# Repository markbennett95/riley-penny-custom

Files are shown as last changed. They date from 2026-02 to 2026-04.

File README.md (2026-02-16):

# Custom Dual OD - Riley Penney

Custom dual drive in a 1590BB - Called the "Chinook Overdrive", it features a Zendrive on one side, and a modified BD-2 on the the other.

## v1.0.0-build
1590BB encl. Works with `1590BB-2` of the [Dual Effect Order Switching Board](https://github.com/markbennett95/dual-effect-order-switching-board). Zendrive schematic is unchanged, using the "version" switch and a DG412. The BD-2 is heavily modified from the original; It features an active baxendall 2-band tone stack, and a gyrator-based 3-way "Mids" switch. Some zener diodes were added in the feedback path of the second gain stage, which went a long ways in cleaning up some of the fizziness inherent in the original version.

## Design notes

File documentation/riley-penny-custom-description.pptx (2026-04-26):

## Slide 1

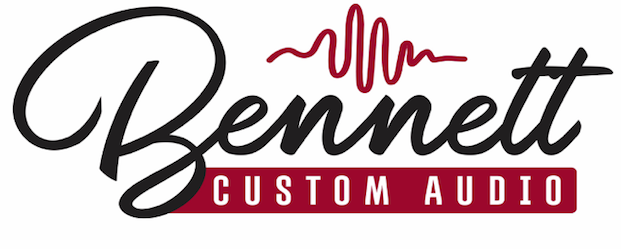
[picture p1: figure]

“Chinook”
Custom Dual Overdrive

Introduction:
This custom-designed pedal features two independent overdrive circuits with order switching. The overdrives are modified versions of the Boss BD2 (“BD2”), and the Zendrive by Hermida Audio (“Zendrive”). The Chinook must be powered by a 9-18VDC, centre-negative power supply, capable of delivering 100mA of current – It does not have room for a battery inside. Like all our pedals, The Chinook was designed and assembled by hand in St. John’s, NL.

Controls:
- BD2 VOL: Controls the output level of the BD2. Turn it up for a louder signal.
- BD2 GAIN: Determines the amount of distortion in the BD2. Turn it up for a more distorted, sustaining tone with more harmonics. Turn it down for a cleaner sound.
- BD2 BASS: Controls the amount of bass in the BD2. It has a centre-notch for a flat response, and may be boost or cut from there by turning it up or down.
- BD2 MIDS: A 3-position switch that sets the mid-range response of the pedal. The CENTRE position gives a flat response. DOWN gives a scooped mid, and UP gives a pushed mids response.
- BD2 TREBLE: Controls the amount of treble in the BD2. It has a centre-notch for a flat response, and may be boost or cut from there by turning it up or down.
- ZEN VOL: Controls the output level of the Zendrive. Turn it up for a louder signal.
- ZEN GAIN: Determines the amount of distortion in the Zendrive. Turn it up for a more distorted, sustaining tone with more harmonics. Turn it down for a cleaner sound.
- ZEN TONE: Controls how warm or bright the tone will be. Turn it up for a bright sound.
- ZEN VERSION SWITCH: Sets the “version” of the Zendrive. Version I is brighter, with asymmetric clipping, less bass, and less overall gain. Version II has more gain, bass, and symmetric clipping for a warmer, fuzzier tone.
- ZEN VOICE: Sets the pre-gain bass of the Zendrive. Turning it down gives a warmer, less distorted sound. Turning it up gives a brighter sound with more overall gain.
- BD2 Footswitch: Toggles the BD2 on or off with true bypass. IF the LED next to it is illuminated, your signal is passing into the effect.
- Order Switch: Sets the order of the two overdrive circuits. UP puts the Zendrive before the BD2 in your signal chain, DOWN puts the BD2 before the Zendrive.
- ZEN Footswitch: Toggles the Zendrive on or off with true bypass. IF the LED next to it is illuminated, your signal is passing into the effect.

V1.0.0

www.bennettcustomaudio.ca
bennettcustomaudio@gmail.com

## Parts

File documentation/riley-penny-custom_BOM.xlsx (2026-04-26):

Value | Qty | Reference | Footprint
2.2k | 4 | R21,R25,R31,R35 | Resistor_SMD:R_0603_1608Metric_Pad0.98x0.95mm_HandSolder
4.7k | 2 | R22,R32 | Resistor_SMD:R_0603_1608Metric_Pad0.98x0.95mm_HandSolder
10k | 5 | R1,R17,R18,R60,R61 | Resistor_SMD:R_0805_2012Metric_Pad1.20x1.40mm_HandSolder
22k | 2 | R2,R3 | Resistor_SMD:R_0805_2012Metric_Pad1.20x1.40mm_HandSolder
33k | 1 | R52 | Resistor_SMD:R_0805_2012Metric_Pad1.20x1.40mm_HandSolder
1M | 3 | R20,R49,R51 | Resistor_SMD:R_0805_2012Metric_Pad1.20x1.40mm_HandSolder
10M | 1 | R6 | Resistor_SMD:R_0805_2012Metric_Pad1.20x1.40mm_HandSolder
47pF | 4 | C17,C18,C31,C35 | Capacitor_SMD:C_0603_1608Metric_Pad1.08x0.95mm_HandSolder
100pF | 3 | C6,C24,C25 | Capacitor_SMD:C_0603_1608Metric_Pad1.08x0.95mm_HandSolder
470pF | 1 | C9 | Capacitor_SMD:C_0603_1608Metric_Pad1.08x0.95mm_HandSolder
100nF | 3 | C14,C44,C45 | Capacitor_SMD:C_0603_1608Metric_Pad1.08x0.95mm_HandSolder
1uF | 1 | C11 | Capacitor_SMD:C_0805_2012Metric_Pad1.18x1.45mm_HandSolder
FerriteBead_Small | 3 | FB1,FB2,FB3 | Inductor_SMD:L_0805_2012Metric_Pad1.15x1.40mm_HandSolder
9V1 Zener | 1 | D1 | Diode_SMD:D_SOD-323_HandSoldering
Q_PMOS_GSD | 1 | Q1 | Package_TO_SOT_SMD:SOT-23_Handsoldering
BC857C | 2 | Q6,Q8 | Package_TO_SOT_SMD:SOT-23_Handsoldering
BC847C | 1 | Q9 | Package_TO_SOT_SMD:SOT-23_Handsoldering
2N7002 | 3 | Q2,Q3,Q4 | Package_TO_SOT_SMD:SOT-23_Handsoldering
LS844 | 2 | Q5,Q7 | Package_TO_SOT_SMD:SOT-23-6_Handsoldering
OPA1642 | 1 | U2 | Package_SO:SOIC-8_3.9x4.9mm_P1.27mm
TLV9352 | 2 | U3,U4 | Package_SO:SOIC-8_3.9x4.9mm_P1.27mm
DG412xY | 1 | U1 | Package_SO:SOIC-16_3.9x9.9mm_P1.27mm
1k | 4 | R8,R14,R36,R50 | bca-footprints:R_L3.6mm_D1.6mm_P5.00mm_Horizontal
1.5k | 2 | R23,R56 | bca-footprints:R_L3.6mm_D1.6mm_P5.00mm_Horizontal
3.9k | 2 | R33,R39 | bca-footprints:R_L3.6mm_D1.6mm_P5.00mm_Horizontal
5.6k | 2 | R38,R54 | bca-footprints:R_L3.6mm_D1.6mm_P5.00mm_Horizontal
6.8k | 3 | R37,R47 | bca-footprints:R_L3.6mm_D1.6mm_P5.00mm_Horizontal
10k | 8 | R7,R10,R11,R13,R19,R44,R58,R59 | bca-footprints:R_L3.6mm_D1.6mm_P5.00mm_Horizontal
15k | 4 | R24,R29,R42,R45 | bca-footprints:R_L3.6mm_D1.6mm_P5.00mm_Horizontal
18k | 1 | R12 | bca-footprints:R_L3.6mm_D1.6mm_P5.00mm_Horizontal
22k | 3 | R34,R43,R46 | bca-footprints:R_L3.6mm_D1.6mm_P5.00mm_Horizontal
56k | 2 | R26,R53 | bca-footprints:R_L3.6mm_D1.6mm_P5.00mm_Horizontal
100k | 3 | R15,R16,R57 | bca-footprints:R_L3.6mm_D1.6mm_P5.00mm_Horizontal
180k | 1 | R41 | bca-footprints:R_L3.6mm_D1.6mm_P5.00mm_Horizontal
330k | 1 | R27 | bca-footprints:R_L3.6mm_D1.6mm_P5.00mm_Horizontal
470k | 5 | R5,R30,R40,R48,R55 | bca-footprints:R_L3.6mm_D1.6mm_P5.00mm_Horizontal
680k | 1 | R9 | bca-footprints:R_L3.6mm_D1.6mm_P5.00mm_Horizontal
1M | 1 | R28 | bca-footprints:R_L3.6mm_D1.6mm_P5.00mm_Horizontal
2.2M | 1 | R4 | bca-footprints:R_L3.6mm_D1.6mm_P5.00mm_Horizontal
1N4148 | 5 | D5,D7,D8,D11,D12 | bca-footprints:Diode_DO-35_P5.00mm
1N5711 | 4 | D2,D3,D4,D6 | bca-footprints:Diode_DO-35_P5.00mm
3v3 Zener | 1 | D9 | bca-footprints:Diode_Zener_DO-35_P5.00mm
4v7 Zener | 1 | D10 | bca-footprints:Diode_Zener_DO-35_P5.00mm
220pF | 1 | C19 | bca-footprints:C_Ceramic_L4.0mm_W2.5mm_P2.50mm
3.3nF | 1 | C7 | bca-footprints:C_Film_L7.2mm_W2.5mm_P5.00mm
3.9nF | 3 | C22,C33,C39 | bca-footprints:C_Film_L7.2mm_W2.5mm_P5.00mm
5.6nF | 3 | C26,C27,C40 | bca-footprints:C_Film_L7.2mm_W2.5mm_P5.00mm
8.2nF | 1 | C36 | bca-footprints:C_Film_L7.2mm_W2.5mm_P5.00mm
15nF | 2 | C34,C37 | bca-footprints:C_Film_L7.2mm_W2.5mm_P5.00mm
18nF | 2 | C15,C28 | bca-footprints:C_Film_L7.2mm_W2.5mm_P5.00mm
33nF | 2 | C30,C38 | bca-footprints:C_Film_L7.2mm_W2.5mm_P5.00mm
47nF | 1 | C21 | bca-footprints:C_Film_L7.2mm_W2.5mm_P5.00mm
68nF | 1 | C29 | bca-footprints:C_Film_L7.2mm_W2.5mm_P5.00mm
0.1uF | 1 | C20 | bca-footprints:C_Film_L7.2mm_W2.5mm_P5.00mm
0.15uF | 1 | C16 | bca-footprints:C_Film_L7.2mm_W3.5mm_P5.00mm
0.22uF | 3 | C4,C5,C8 | bca-footprints:C_Film_L7.2mm_W3.5mm_P5.00mm
0.47uF | 2 | C3,C10 | bca-footprints:C_Film_L7.2mm_W3.5mm_P5.00mm
1uF | 1 | C23 | bca-footprints:C_Film_L7.2mm_W3.5mm_P5.00mm
10uF | 2 | C32,C41 | bca-footprints:CP_Radial_D4.0mm_P1.50mm
100uF | 6 | C1,C2,C12,C13,C42,C43 | bca-footprints:CP_Radial_D6.3mm_P2.50mm
SW_DIP_SPDT_2pos | 1 | SW3 | bca-footprints:DIP-8_W7.62mm_Socket
Barrel_Jack_Switch | 1 | J1 | bca-footprints:DC_Jack_DC005
AudioJack_TRS | 2 | J2,J3 | bca-footprints:Rean_NYS215
GNDSpring | 1 | G1 | bca-footprints:Keystone_628
10kC | 1 | RV1 | bca-footprints:R_POT
50kB | 1 | RV3 | bca-footprints:R_POT
100kA | 2 | RV4,RV6 | bca-footprints:R_POT
100k-CD | 2 | RV7,RV8 | bca-footprints:R_POT
1MA | 1 | RV2 | bca-footprints:R_POT
250kA | 1 | RV5 | bca-footprints:R_POT_DUAL
SW_DPDT_x2 | 1 | SW2 | bca-footprints:SW_Toggle_DPDT_SolderLug
SW_SPDT | 1 | SW1 | bca-footprints:SW_Toggle_SPDT_SolderLug

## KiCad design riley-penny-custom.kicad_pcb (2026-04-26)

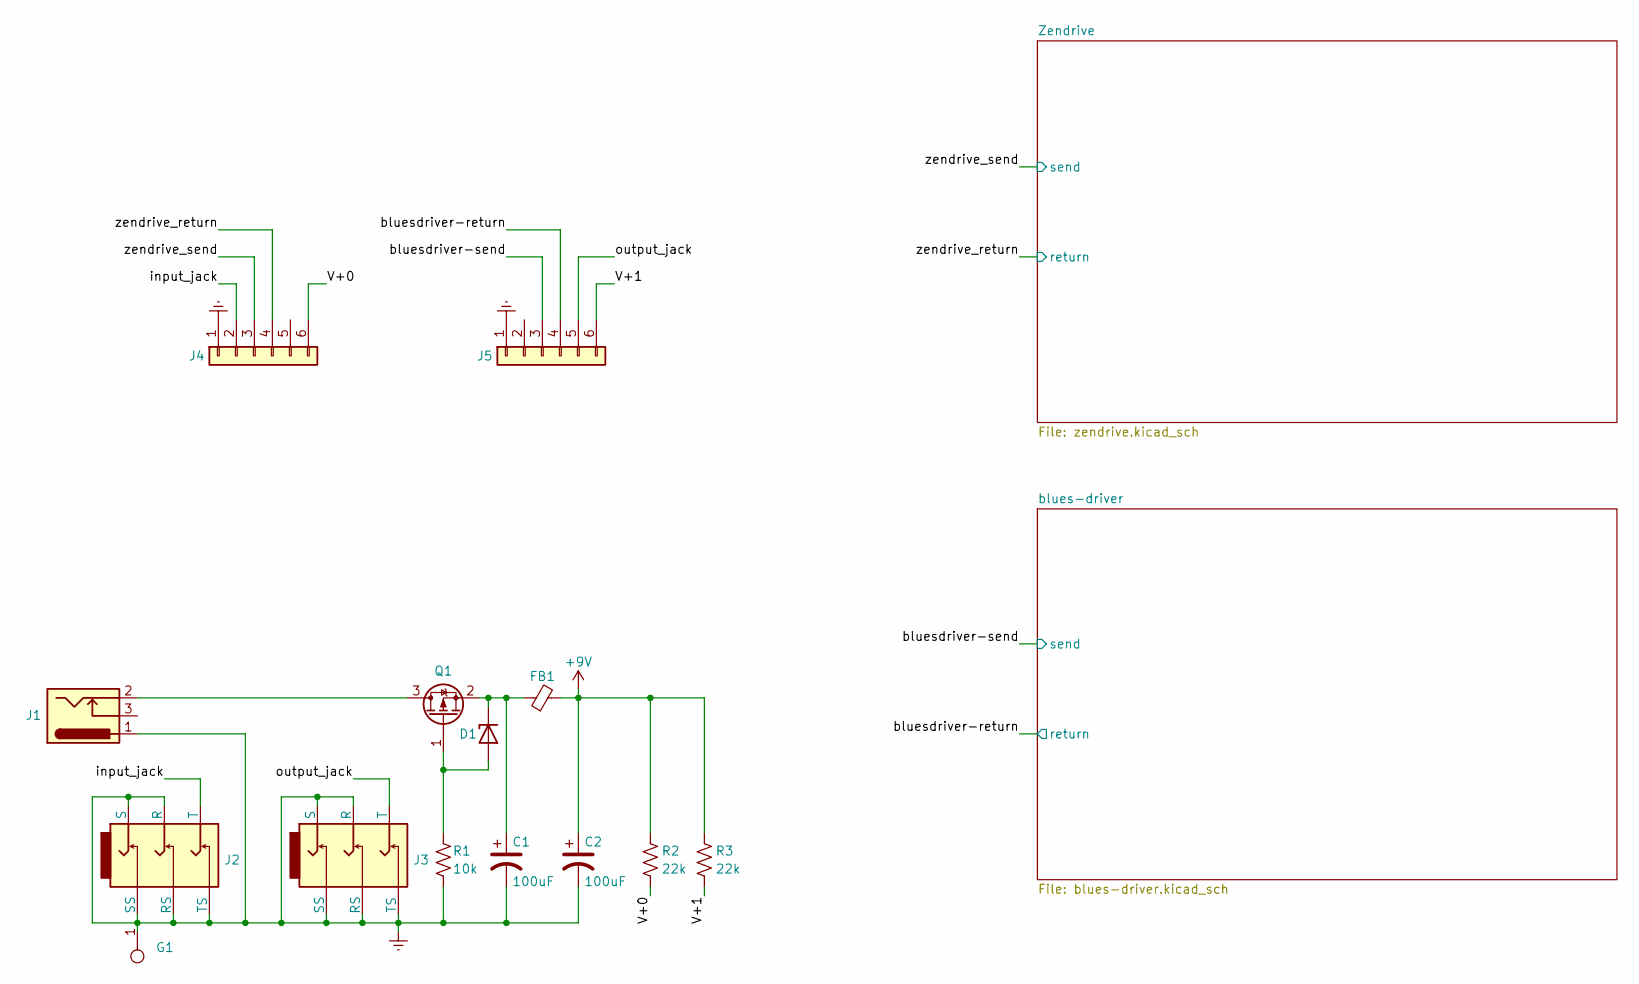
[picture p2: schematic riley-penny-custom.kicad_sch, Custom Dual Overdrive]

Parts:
C1, C2: 100uF; CP_Radial_D6.3mm_P2.50mm
D1: 9V1 Zener; D_SOD-323_HandSoldering
FB1: FerriteBead_Small; L_0805_2012Metric_Pad1.15x1.40mm_HandSolder
G1: GNDSpring; Keystone_628
J1: Barrel_Jack_Switch; DC_Jack_DC005
J2, J3: AudioJack_TRS; Rean_NYS215
J4, J5: Conn_01x06; Pin_Header_Straight_1x06_Pitch2.54mm
Q1: Q_PMOS_GSD; SOT-23_Handsoldering
R1: 10k; R_0805_2012Metric_Pad1.20x1.40mm_HandSolder
R2, R3: 22k; R_0805_2012Metric_Pad1.20x1.40mm_HandSolder

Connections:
+9V: C2.1, FB1.2, R2.2, R3.2; also elsewhere on the board
/V+0: J4.6, R2.1
/V+1: J5.6, R3.1
/bluesdriver-return: J5.4; also elsewhere on the board
/bluesdriver-send: J5.3; also elsewhere on the board
/input_jack: J2.1 (T), J4.2
/output_jack: J3.1 (T), J5.5
/zendrive_return: J4.4; also elsewhere on the board
/zendrive_send: J4.3; also elsewhere on the board
Earth: C1.2, C2.2, G1.1, J1.1, J2.2 (R), J2.3 (S), J2.4 (TS), J2.5 (RS), J2.6 (SS), J3.2 (R), J3.3 (S), J3.4 (TS), J3.5 (RS), J3.6 (SS), J4.1, J5.1, R1.1; also elsewhere on the board
unnamed: D1.2 (A), Q1.1 (G), R1.2
unnamed: C1.1, D1.1 (K), FB1.1, Q1.2 (S)
unnamed: J1.2, Q1.3 (D)

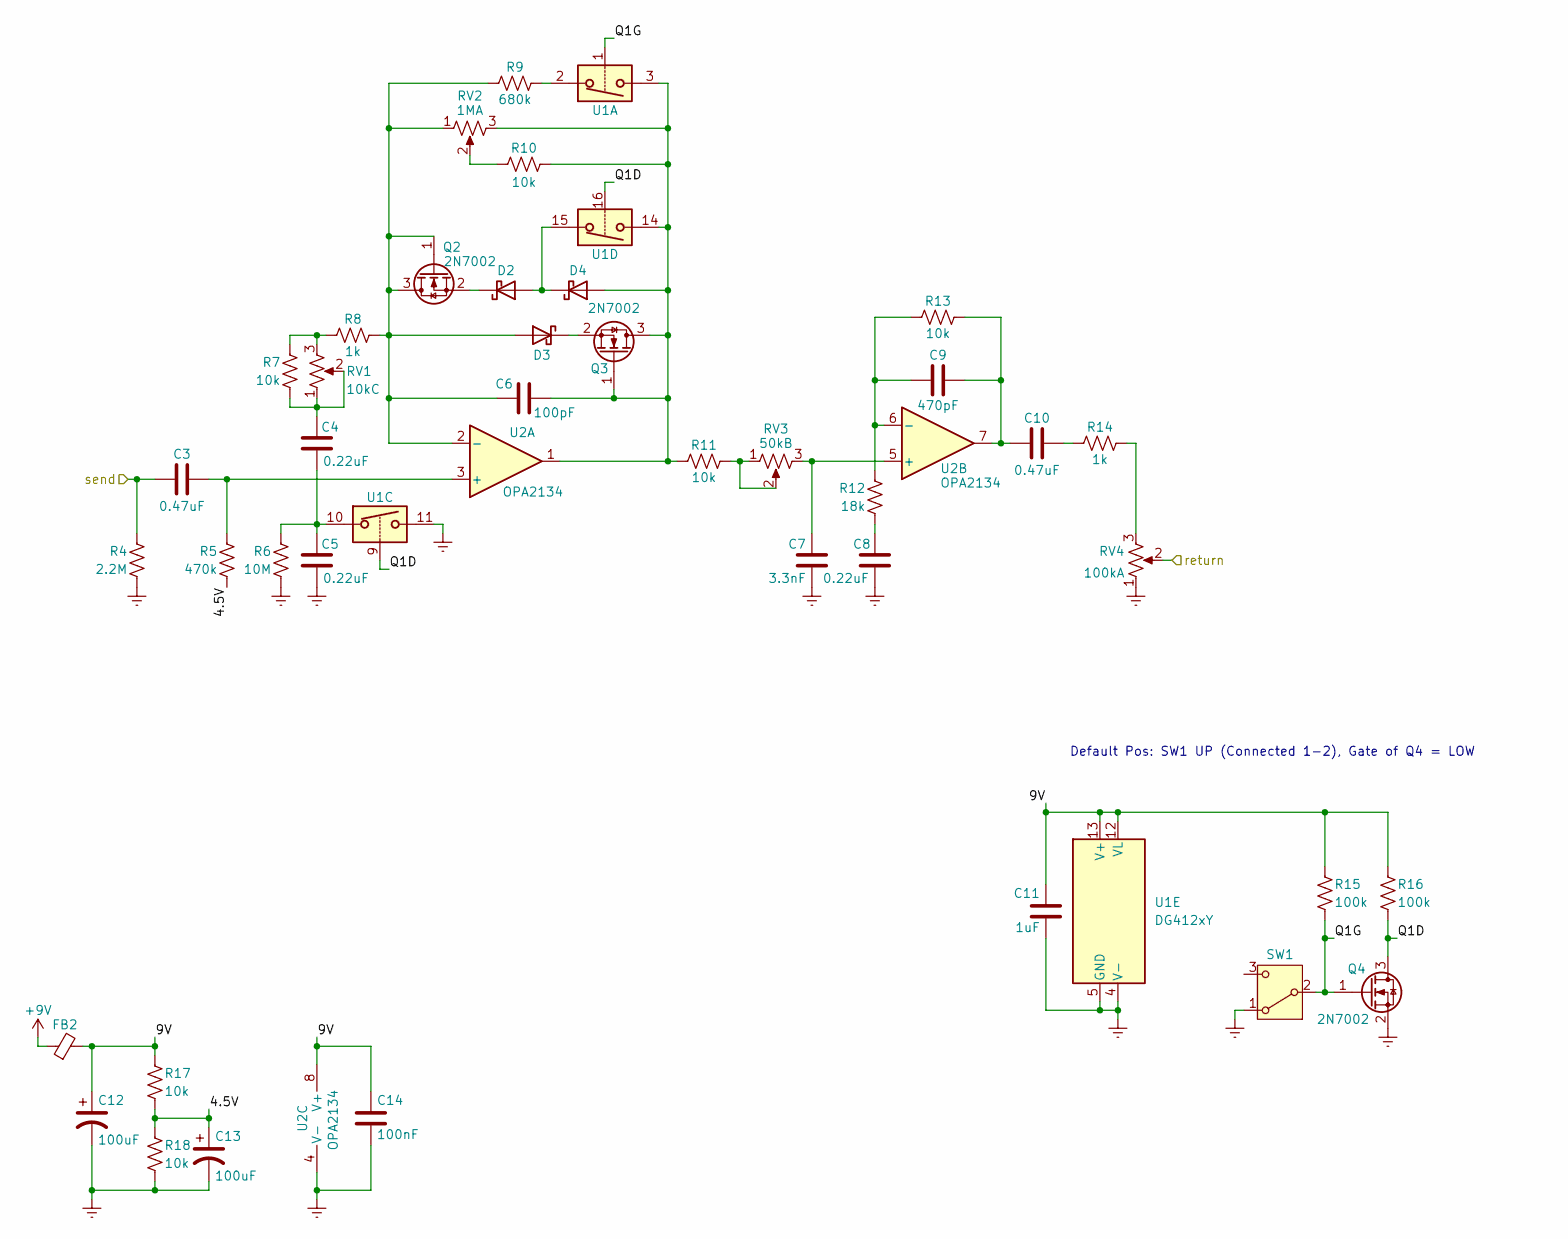
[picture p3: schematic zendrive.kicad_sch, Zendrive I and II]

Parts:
C3, C10: 0.47uF; C_Film_L7.2mm_W3.5mm_P5.00mm
C4, C5, C8: 0.22uF; C_Film_L7.2mm_W3.5mm_P5.00mm
C6: 100pF; C_0603_1608Metric_Pad1.08x0.95mm_HandSolder
C7: 3.3nF; C_Film_L7.2mm_W2.5mm_P5.00mm
C9: 470pF; C_0603_1608Metric_Pad1.08x0.95mm_HandSolder
C11: 1uF; C_0805_2012Metric_Pad1.18x1.45mm_HandSolder
C12, C13: 100uF; CP_Radial_D6.3mm_P2.50mm
C14: 100nF; C_0603_1608Metric_Pad1.08x0.95mm_HandSolder
D2, D3, D4: 1N5711; Diode_DO-35_P5.00mm
FB2: FerriteBead_Small; L_0805_2012Metric_Pad1.15x1.40mm_HandSolder
Q2, Q3, Q4: 2N7002; SOT-23_Handsoldering
R4: 2.2M; R_L3.6mm_D1.6mm_P5.00mm_Horizontal
R5: 470k; R_L3.6mm_D1.6mm_P5.00mm_Horizontal
R6: 10M; R_0805_2012Metric_Pad1.20x1.40mm_HandSolder
R7, R10, R11, R13: 10k; R_L3.6mm_D1.6mm_P5.00mm_Horizontal
R8, R14: 1k; R_L3.6mm_D1.6mm_P5.00mm_Horizontal
R9: 680k; R_L3.6mm_D1.6mm_P5.00mm_Horizontal
R12: 18k; R_L3.6mm_D1.6mm_P5.00mm_Horizontal
R15, R16: 100k; R_L3.6mm_D1.6mm_P5.00mm_Horizontal
R17, R18: 10k; R_0805_2012Metric_Pad1.20x1.40mm_HandSolder
RV1: 10kC; R_POT
RV2: 1MA; R_POT
RV3: 50kB; R_POT
RV4: 100kA; R_POT
SW1: SW_SPDT; SW_Toggle_SPDT_SolderLug
U1: DG412xY; SOIC-16_3.9x9.9mm_P1.27mm
U2: OPA2134; SOIC-8_3.9x4.9mm_P1.27mm

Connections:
+9V: FB2.1; also elsewhere on the board
/Zendrive/4.5V: C13.1, R5.1, R17.1, R18.2
/Zendrive/9V: C11.1, C12.1, C14.1, FB2.2, R15.2, R16.2, R17.2, U1.12 (VL), U1.13 (V+), U2.8 (V+)
/Zendrive/Q1D: Q4.3 (D), R16.1, U1.9, U1.16
/Zendrive/Q1G: Q4.1 (G), R15.1, SW1.2 (B), U1.1
/zendrive_return: RV4.2; also elsewhere on the board
/zendrive_send: C3.1, R4.2; also elsewhere on the board
Earth: C5.1, C7.2, C8.1, C11.2, C12.2, C13.2, C14.2, Q4.2 (S), R4.1, R6.1, R18.1, RV4.1, SW1.1 (A), U1.4 (V-), U1.5 (GND), U1.11, U2.4 (V-); also elsewhere on the board
unnamed: C4.1, C5.2, R6.2, U1.10
unnamed: C4.2, R7.1, RV1.1, RV1.2
unnamed: C8.2, R12.1
unnamed: C9.2, C10.1, R13.2, U2.7
unnamed: C10.2, R14.1
unnamed: D2.2 (A), D4.1 (K), U1.15
unnamed: D2.1 (K), Q2.2 (S)
unnamed: C6.1, D3.2 (A), Q2.1 (G), Q2.3 (D), R8.2, R9.1, RV2.1, U2.2 (-)
unnamed: D3.1 (K), Q3.2 (S)
unnamed: C6.2, D4.2 (A), Q3.1 (G), Q3.3 (D), R10.2, R11.1, RV2.3, U1.3, U1.14, U2.1
unnamed: R7.2, R8.1, RV1.3
unnamed: R9.2, U1.2
unnamed: R10.1, RV2.2
unnamed: R11.2, RV3.1, RV3.2
unnamed: R14.2, RV4.3
unnamed: C3.2, R5.2, U2.3 (+)
unnamed: C7.1, RV3.3, U2.5 (+)
unnamed: C9.1, R12.2, R13.1, U2.6 (-)

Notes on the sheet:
Default Pos: SW1 UP (Connected 1-2), Gate of Q4 = LOW

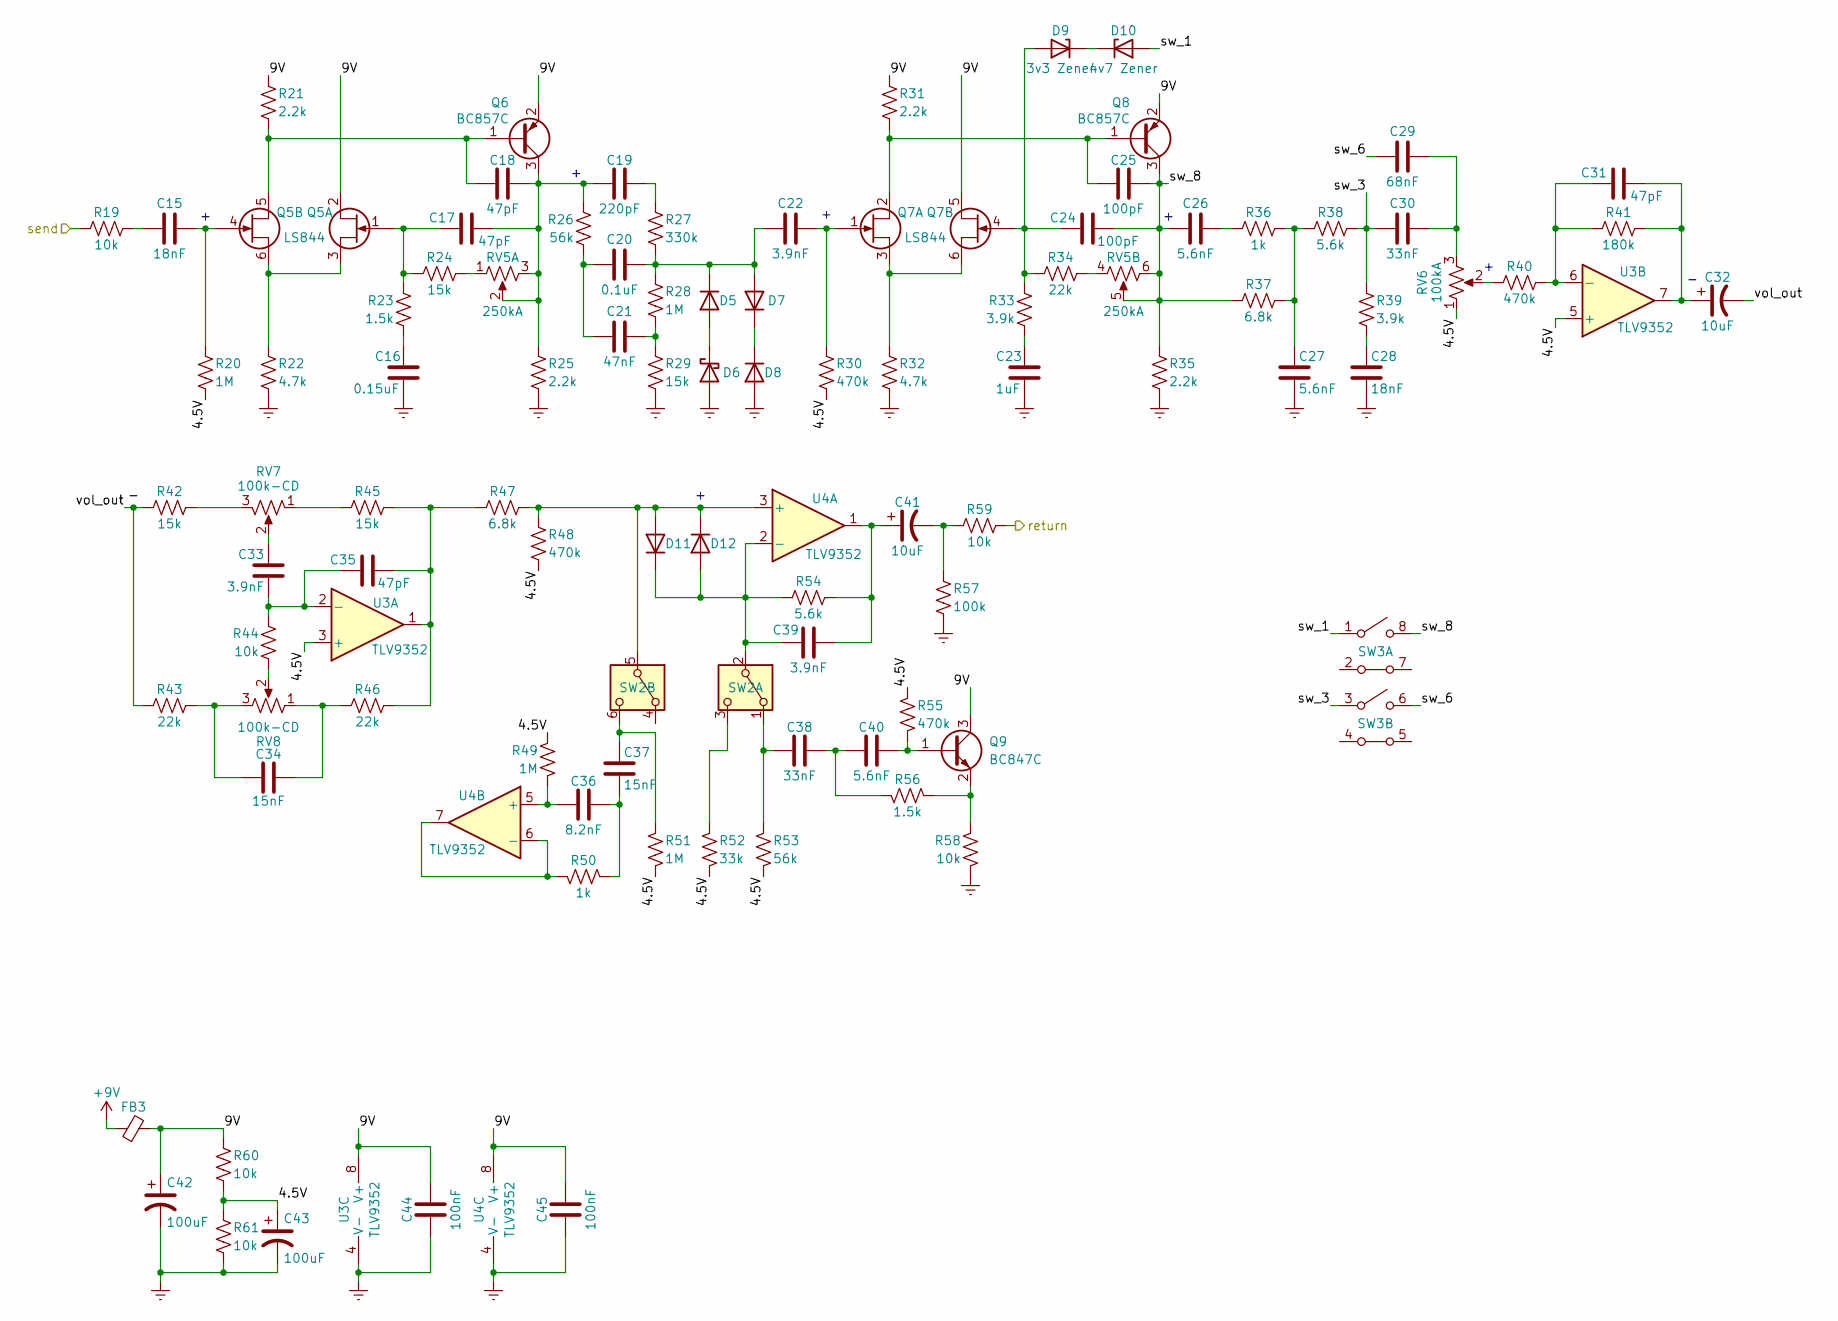
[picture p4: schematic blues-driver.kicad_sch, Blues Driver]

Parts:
C15, C28: 18nF; C_Film_L7.2mm_W2.5mm_P5.00mm
C16: 0.15uF; C_Film_L7.2mm_W3.5mm_P5.00mm
C17, C18, C31, C35: 47pF; C_0603_1608Metric_Pad1.08x0.95mm_HandSolder
C19: 220pF; C_Ceramic_L4.0mm_W2.5mm_P2.50mm
C20: 0.1uF; C_Film_L7.2mm_W2.5mm_P5.00mm
C21: 47nF; C_Film_L7.2mm_W2.5mm_P5.00mm
C22, C33, C39: 3.9nF; C_Film_L7.2mm_W2.5mm_P5.00mm
C23: 1uF; C_Film_L7.2mm_W3.5mm_P5.00mm
C24, C25: 100pF; C_0603_1608Metric_Pad1.08x0.95mm_HandSolder
C26, C27, C40: 5.6nF; C_Film_L7.2mm_W2.5mm_P5.00mm
C29: 68nF; C_Film_L7.2mm_W2.5mm_P5.00mm
C30, C38: 33nF; C_Film_L7.2mm_W2.5mm_P5.00mm
C32, C41: 10uF; CP_Radial_D4.0mm_P1.50mm
C34, C37: 15nF; C_Film_L7.2mm_W2.5mm_P5.00mm
C36: 8.2nF; C_Film_L7.2mm_W2.5mm_P5.00mm
C42, C43: 100uF; CP_Radial_D6.3mm_P2.50mm
C44, C45: 100nF; C_0603_1608Metric_Pad1.08x0.95mm_HandSolder
D5, D7, D8, D11, D12: 1N4148; Diode_DO-35_P5.00mm
D6: 1N5711; Diode_DO-35_P5.00mm
D9: 3v3 Zener; Diode_Zener_DO-35_P5.00mm
D10: 4v7 Zener; Diode_Zener_DO-35_P5.00mm
FB3: FerriteBead_Small; L_0805_2012Metric_Pad1.15x1.40mm_HandSolder
Q5, Q7: LS844; SOT-23-6_Handsoldering
Q6, Q8: BC857C; SOT-23_Handsoldering
Q9: BC847C; SOT-23_Handsoldering
R19, R44, R58, R59: 10k; R_L3.6mm_D1.6mm_P5.00mm_Horizontal
R20, R49, R51: 1M; R_0805_2012Metric_Pad1.20x1.40mm_HandSolder
R21, R25, R31, R35: 2.2k; R_0603_1608Metric_Pad0.98x0.95mm_HandSolder
R22, R32: 4.7k; R_0603_1608Metric_Pad0.98x0.95mm_HandSolder
R23, R56: 1.5k; R_L3.6mm_D1.6mm_P5.00mm_Horizontal
R24, R29, R42, R45: 15k; R_L3.6mm_D1.6mm_P5.00mm_Horizontal
R26, R53: 56k; R_L3.6mm_D1.6mm_P5.00mm_Horizontal
R27: 330k; R_L3.6mm_D1.6mm_P5.00mm_Horizontal
R28: 1M; R_L3.6mm_D1.6mm_P5.00mm_Horizontal
R30, R40, R48, R55: 470k; R_L3.6mm_D1.6mm_P5.00mm_Horizontal
R33, R39: 3.9k; R_L3.6mm_D1.6mm_P5.00mm_Horizontal
R34, R43, R46: 22k; R_L3.6mm_D1.6mm_P5.00mm_Horizontal
R36, R50: 1k; R_L3.6mm_D1.6mm_P5.00mm_Horizontal
R37, R47: 6.8k; R_L3.6mm_D1.6mm_P5.00mm_Horizontal
R38, R54: 5.6k; R_L3.6mm_D1.6mm_P5.00mm_Horizontal
R41: 180k; R_L3.6mm_D1.6mm_P5.00mm_Horizontal
R52: 33k; R_0805_2012Metric_Pad1.20x1.40mm_HandSolder
R57: 100k; R_L3.6mm_D1.6mm_P5.00mm_Horizontal
R60, R61: 10k; R_0805_2012Metric_Pad1.20x1.40mm_HandSolder
RV5: 250kA; R_POT_DUAL
RV6: 100kA; R_POT
RV7, RV8: 100k-CD; R_POT
SW2: SW_DPDT_x2; SW_Toggle_DPDT_SolderLug
SW3: SW_DIP_SPDT_2pos; DIP-8_W7.62mm_Socket
U3, U4: TLV9352; SOIC-8_3.9x4.9mm_P1.27mm

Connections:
+9V: FB3.1; also elsewhere on the board
/blues-driver/4.5V: C43.1, R20.1, R30.1, R48.1, R49.2, R51.1, R52.1, R53.1, R55.2, R60.1, R61.2, RV6.1, U3.3 (+), U3.5 (+)
/blues-driver/9V: C42.1, C44.1, C45.1, FB3.2, Q5.2 (D1), Q6.2 (E), Q7.5 (D2), Q8.2 (E), Q9.3 (C), R21.2, R31.2, R60.2, U3.8 (V+), U4.8 (V+)
/blues-driver/sw_1: D10.2 (A), SW3.1 (C)
/blues-driver/sw_3: C30.1, R38.2, R39.2, SW3.3 (C)
/blues-driver/sw_6: C29.1, SW3.6 (A)
/blues-driver/sw_8: C24.2, C25.2, C26.1, Q8.3 (C), R35.2, R37.1, RV5.5, RV5.6, SW3.8 (A)
/blues-driver/vol_out: C32.2, R42.1, R43.1
/bluesdriver-return: R59.2; also elsewhere on the board
/bluesdriver-send: R19.1; also elsewhere on the board
Earth: C16.2, C23.2, C27.1, C28.1, C42.2, C43.2, C44.2, C45.2, D6.2 (A), D8.2 (A), R22.1, R25.1, R29.1, R32.1, R35.1, R57.1, R58.1, R61.1, U3.4 (V-), U4.4 (V-); also elsewhere on the board
unnamed: C15.1, R19.2
unnamed: C16.1, R23.1
unnamed: C19.2, R27.2
unnamed: C20.1, C21.1, R26.1
unnamed: C21.2, R28.1, R29.2
unnamed: C23.1, R33.1
unnamed: C26.2, R36.1
unnamed: C27.2, R36.2, R37.2, R38.1
unnamed: C28.2, R39.1
unnamed: C29.2, C30.2, RV6.3
unnamed: C31.2, C32.1, R41.2, U3.7
unnamed: C33.2, RV7.2
unnamed: C34.1, R46.1, RV8.1
unnamed: C34.2, R43.2, RV8.3
unnamed: C35.2, R45.2, R46.2, R47.1, U3.1
unnamed: C36.2, C37.1, R50.1
unnamed: C38.2, C40.1, R56.2
unnamed: C39.2, C41.1, R54.2, U4.1
unnamed: C41.2, R57.2, R59.1
unnamed: D5.2 (A), D6.1 (K)
unnamed: C20.2, C22.1, D5.1 (K), D7.2 (A), R27.1, R28.2
unnamed: D7.1 (K), D8.1 (K)
unnamed: C24.1, D9.2 (A), Q7.4 (G1), R33.2, R34.1
unnamed: D9.1 (K), D10.1 (K)
unnamed: D11.2 (A), D12.1 (K), R47.2, R48.2, SW2.5 (B), U4.3 (+)
unnamed: C39.1, D11.1 (K), D12.2 (A), R54.1, SW2.2 (B), U4.2 (-)
unnamed: C17.1, Q5.1 (G1), R23.2, R24.1
unnamed: Q5.3 (S1), Q5.6 (S1), R22.2
unnamed: C18.1, Q5.5 (D2), Q6.1 (B), R21.1
unnamed: C15.2, Q5.4 (G1), R20.2
unnamed: C17.2, C18.2, C19.1, Q6.3 (C), R25.2, R26.2, RV5.2 (5), RV5.3 (6)
unnamed: C25.1, Q7.2 (D1), Q8.1 (B), R31.1
unnamed: C22.2, Q7.1 (G1), R30.2
unnamed: Q7.3 (S1), Q7.6 (S1), R32.2
unnamed: C40.2, Q9.1 (B), R55.1
unnamed: Q9.2 (E), R56.1, R58.2
unnamed: R34.2, RV5.4
unnamed: R40.1, RV6.2
unnamed: R42.2, RV7.3
unnamed: R44.1, RV8.2
unnamed: R45.1, RV7.1
unnamed: R24.2, RV5.1 (4)
unnamed: C38.1, R53.2, SW2.1 (A)
unnamed: R52.2, SW2.3 (C)
unnamed: C37.2, R51.2, SW2.6 (C)
unnamed: C33.1, C35.1, R44.2, U3.2 (-)
unnamed: C31.1, R40.2, R41.1, U3.6 (-)
unnamed: C36.1, R49.1, U4.5 (+)
unnamed: R50.2, U4.6 (-), U4.7

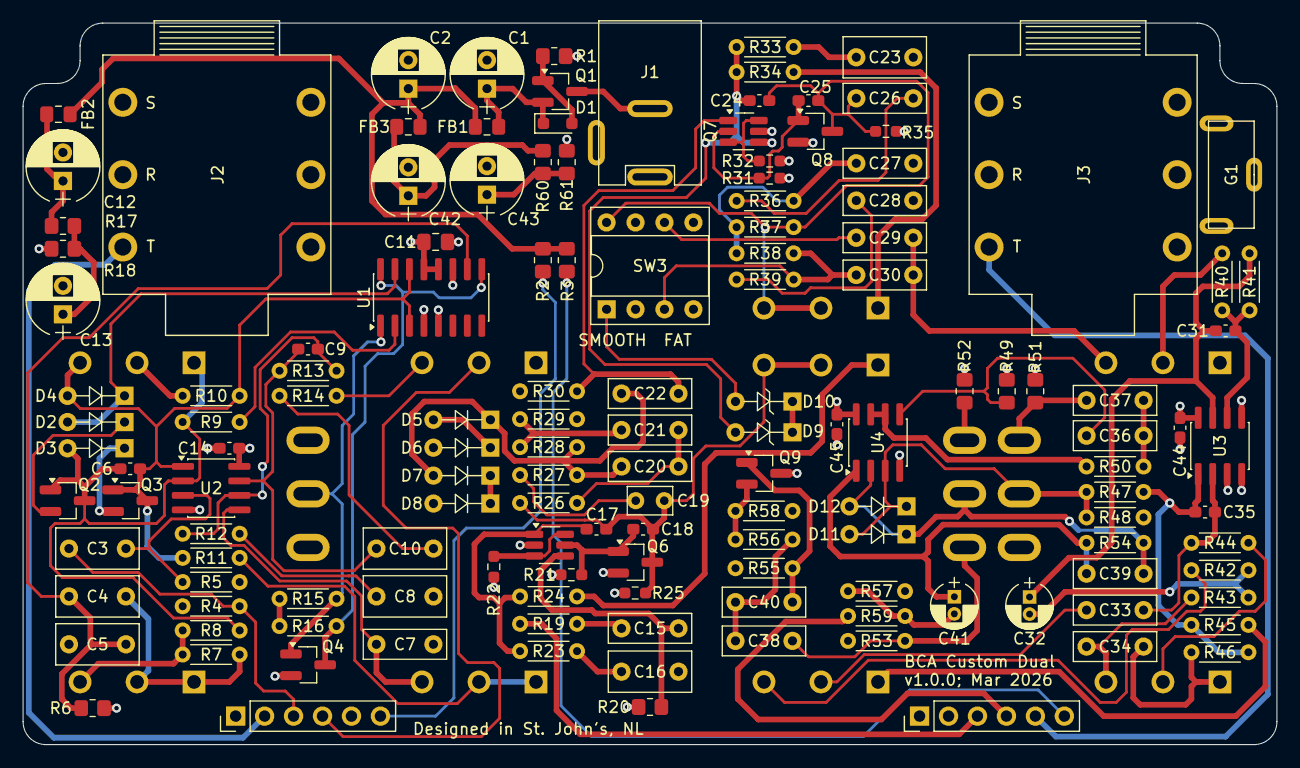
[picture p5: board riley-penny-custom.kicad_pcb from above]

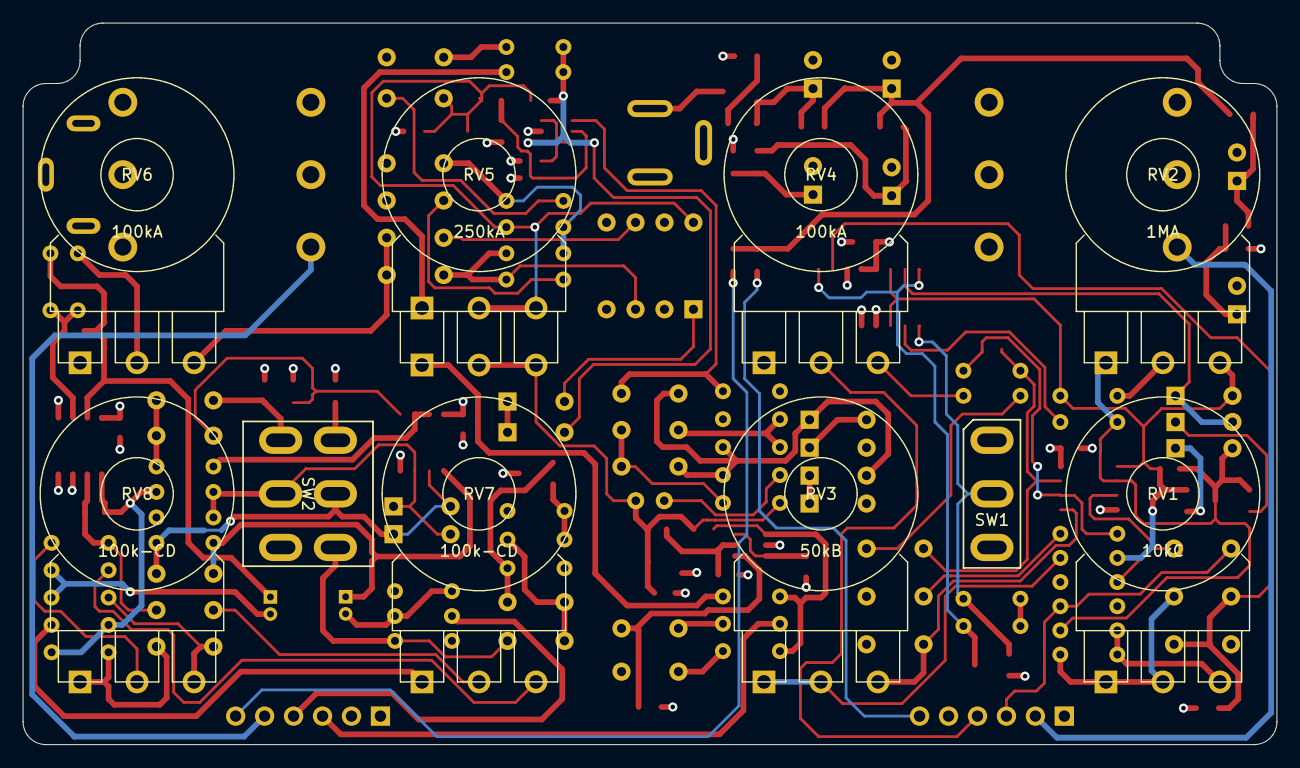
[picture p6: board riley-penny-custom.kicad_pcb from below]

Board: 4 copper layers, 110.0 x 63.3 mm, 151 parts (2 on the bottom side), 91 nets.

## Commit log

2026-01-19 renamed files, added schematics
    [blues-driver.kicad_sch, kicad-template-1590BB.kicad_sch, riley-penny-custom.kicad_pcb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]
2026-02-16 finished schematics, started PCB
    [blues-driver.kicad_sch, riley-penny-custom.kicad_pcb, riley-penny-custom.kicad_sch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]
2026-02-17 initial layout
    [blues-driver.kicad_sch, riley-penny-custom.kicad_pcb, zendrive.kicad_sch]
2026-03-06 first draft PCB
    [blues-driver.kicad_sch, riley-penny-custom.kicad_pcb, zendrive.kicad_sch]
2026-03-13 generated production files
    [blues-driver.kicad_sch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]
2026-04-26 re-generated gerbers, finalized BOM
    [blues-driver.kicad_sch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]
